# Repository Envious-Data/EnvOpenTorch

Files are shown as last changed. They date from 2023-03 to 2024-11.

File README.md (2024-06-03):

# EnvOpenTorch
 A open source rechargable LED Torch

## Notes
This design is a bit jank and can certaily do with some improvement, If you feel like doing that then please do so and make a PR.

Generally speaking is to have a decently powerful open source LED torch, Im hoping for 10K lumens and some basic brightness control, anything else is bonnus features but there are some i'd like such as PD charging and being able to act as a battery bank if needed.

## Future plans
Im probably going to sell this as a full unit or kit other than the need to supply your own cells, I havent decided on 3S2P or 6S1P but for the time being the charge circuit can handle upto 4S.

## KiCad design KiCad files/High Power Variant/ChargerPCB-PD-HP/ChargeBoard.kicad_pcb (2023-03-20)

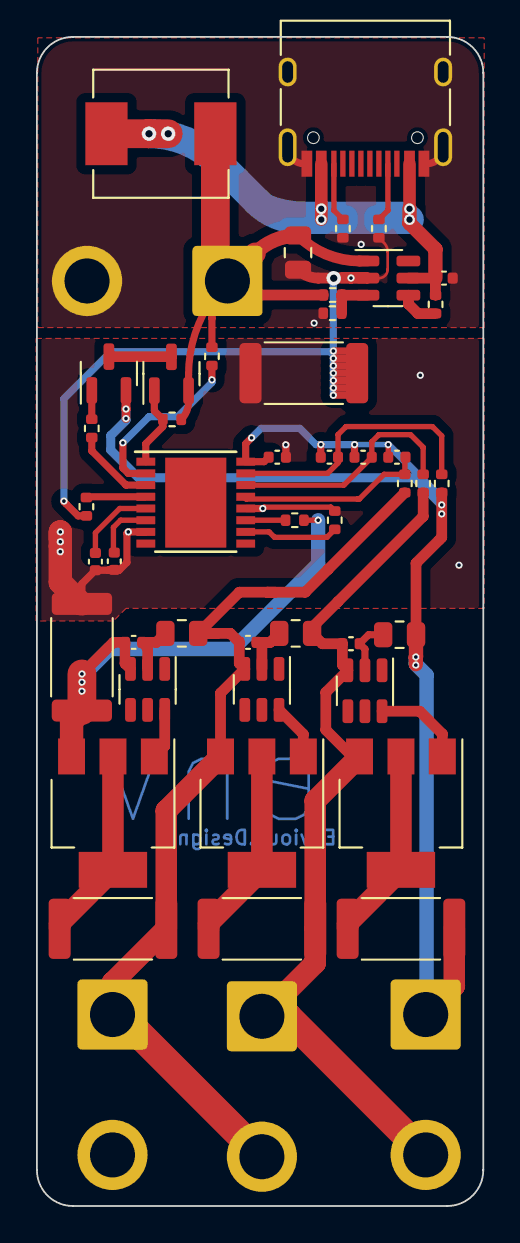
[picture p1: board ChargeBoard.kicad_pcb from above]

Board: 2 copper layers, 24.8 x 65.0 mm, 49 parts (0 on the bottom side), 34 nets.

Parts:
BAT1, BAT2, BAT3: Conn_01x02; SolderWire-2sqmm_1x02_P7.8mm_D2mm_OD3.9mm
C1, C2, C3, C6, C7, C8, C9, C10: 0.1uF 0402; C_0402_1005Metric
C4: 22uF 0402; C_0402_1005Metric
C5: 22uF 0805 25V; C_0805_2012Metric
C11: 2.2uF 0402; C_0402_1005Metric
J1: USB_C_Receptacle_USB2.0; USB_C_Receptacle_HRO_TYPE-C-31-M-12
J101: Conn_01x02; SolderWire-2sqmm_1x02_P7.8mm_D2mm_OD3.9mm
L1: 22uH 10A; L_Sunlord_MWSA0605S
Q1, Q2, Q3: BSP89; SOT-223-3_TabPin2
Q4, Q5: AO3401A; SOT-23
R1, R4, R6: 47 2512; R_2512_6332Metric
R2, R3, R5: 100 0805; R_0805_2012Metric
R7: 10K 0402; R_0402_1005Metric
R8, R9, R21, R22: 5.1K 0402; R_0402_1005Metric
R10: 62K 0402; R_0402_1005Metric
R11: 3K 0402; R_0402_1005Metric
R18, R19, R20, R25, R26, R27: 1K 0402; R_0402_1005Metric
R23: 1M 0402; R_0402_1005Metric
R24: 0r 2512; R_2512_6332Metric
R103: 51r 2512; R_2512_6332Metric
U1, U2, U3: HY2213; SOT-23-6
U4: MT3608; SOT-23-6
U9: 8254; HTSSOP-16-1EP_4.4x5mm_P0.65mm_EP3.4x5mm

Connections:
+12V: C5.1, J101.1, L1.2, Q4.2 (S), R10.1, R22.2, R23.2, U4.1 (SW)
/VDD: BAT3.1, C6.1, C7.1, C8.1, C11.1, Q5.2 (S), R5.1, R6.1, R27.2, U9.16 (VDD)
/VSS: C9.2, C10.2, C11.2, R18.2, R24.2, R103.2, U9.7 (VSS), U9.12 (VCC4)
GND: C4.2, C5.2, J1.A1 (GND), J1.A12 (GND), J1.B1 (GND), J1.B12 (GND), J1.S1 (SHIELD), J101.2, R8.1, R9.1, R11.2, R20.1, R24.1, U4.2 (GND)
unnamed: BAT1.1, BAT2.2, C2.2, Q2.3 (S), R1.1, R2.1, R25.2, U2.3 (VSS)
unnamed: BAT1.2, C1.2, Q1.3 (S), R19.2, R103.1, U1.3 (VSS)
unnamed: BAT2.1, BAT3.2, C3.2, Q3.3 (S), R3.1, R4.1, R26.2, U3.3 (VSS)
unnamed: J1.A5 (CC1), R8.2
unnamed: J1.B5 (CC2), R9.2
unnamed: Q1.2 (D), R1.2
unnamed: Q1.1 (G), U1.6 (Out)
unnamed: Q2.2 (D), R4.2
unnamed: Q2.1 (G), U2.6 (Out)
unnamed: Q3.2 (D), R6.2
unnamed: Q3.1 (G), U3.6 (Out)
unnamed: Q4.3 (D), Q5.3 (D)
unnamed: Q4.1 (G), R23.1, U9.1 (COP)
unnamed: Q5.1 (G), R21.2
unnamed: C1.1, R2.2, U1.2 (VDD)
unnamed: C2.1, R3.2, U2.2 (VDD)
unnamed: C3.1, R5.2, U3.2 (VDD)
unnamed: R7.1, U4.4 (EN)
unnamed: R10.2, R11.1, U4.3 (FB)
unnamed: C9.1, U9.6 (CCT)
unnamed: C10.1, U9.5 (CDT)
unnamed: R19.1, U9.11 (CTL)
unnamed: R21.1, U9.3 (DOP)
unnamed: R18.1, U9.10 (SEL)
unnamed: C6.2, R27.1, U9.15 (VCC1)
unnamed: C7.2, R26.1, U9.14 (VCC2)
unnamed: C8.2, R25.1, U9.13 (VCC3)
unnamed: R20.2, U9.4 (VINI)
unnamed: R22.1, U9.2 (VMP)
VBUS: C4.1, J1.A4 (VBUS), J1.A9 (VBUS), J1.B4 (VBUS), J1.B9 (VBUS), L1.1, R7.2, U4.5 (IN)

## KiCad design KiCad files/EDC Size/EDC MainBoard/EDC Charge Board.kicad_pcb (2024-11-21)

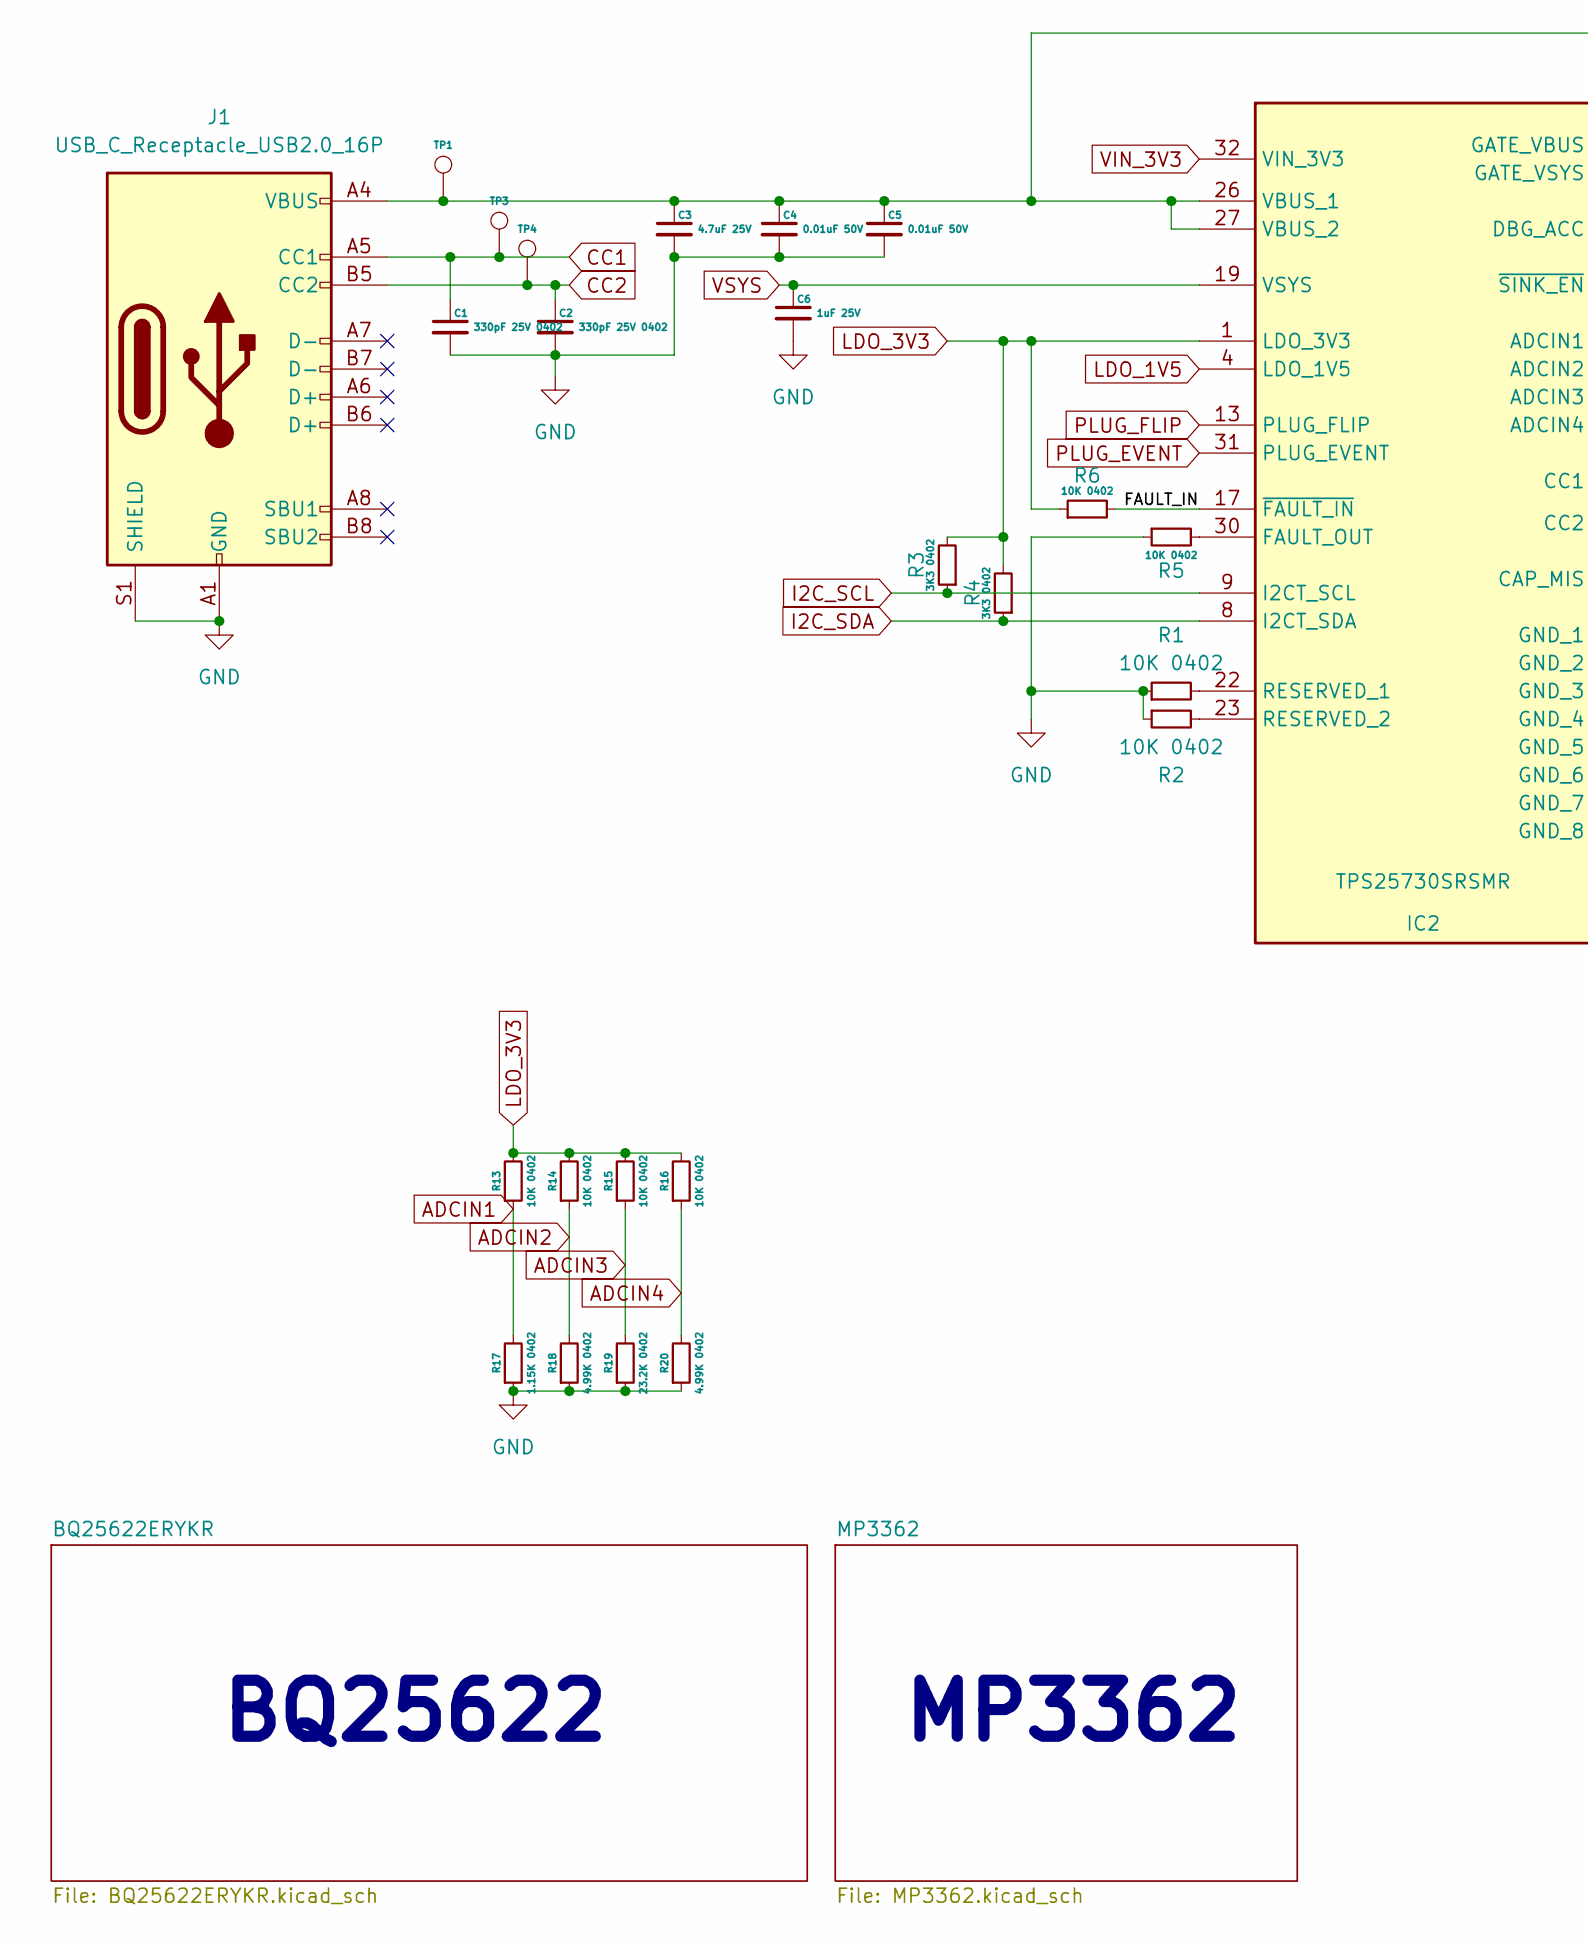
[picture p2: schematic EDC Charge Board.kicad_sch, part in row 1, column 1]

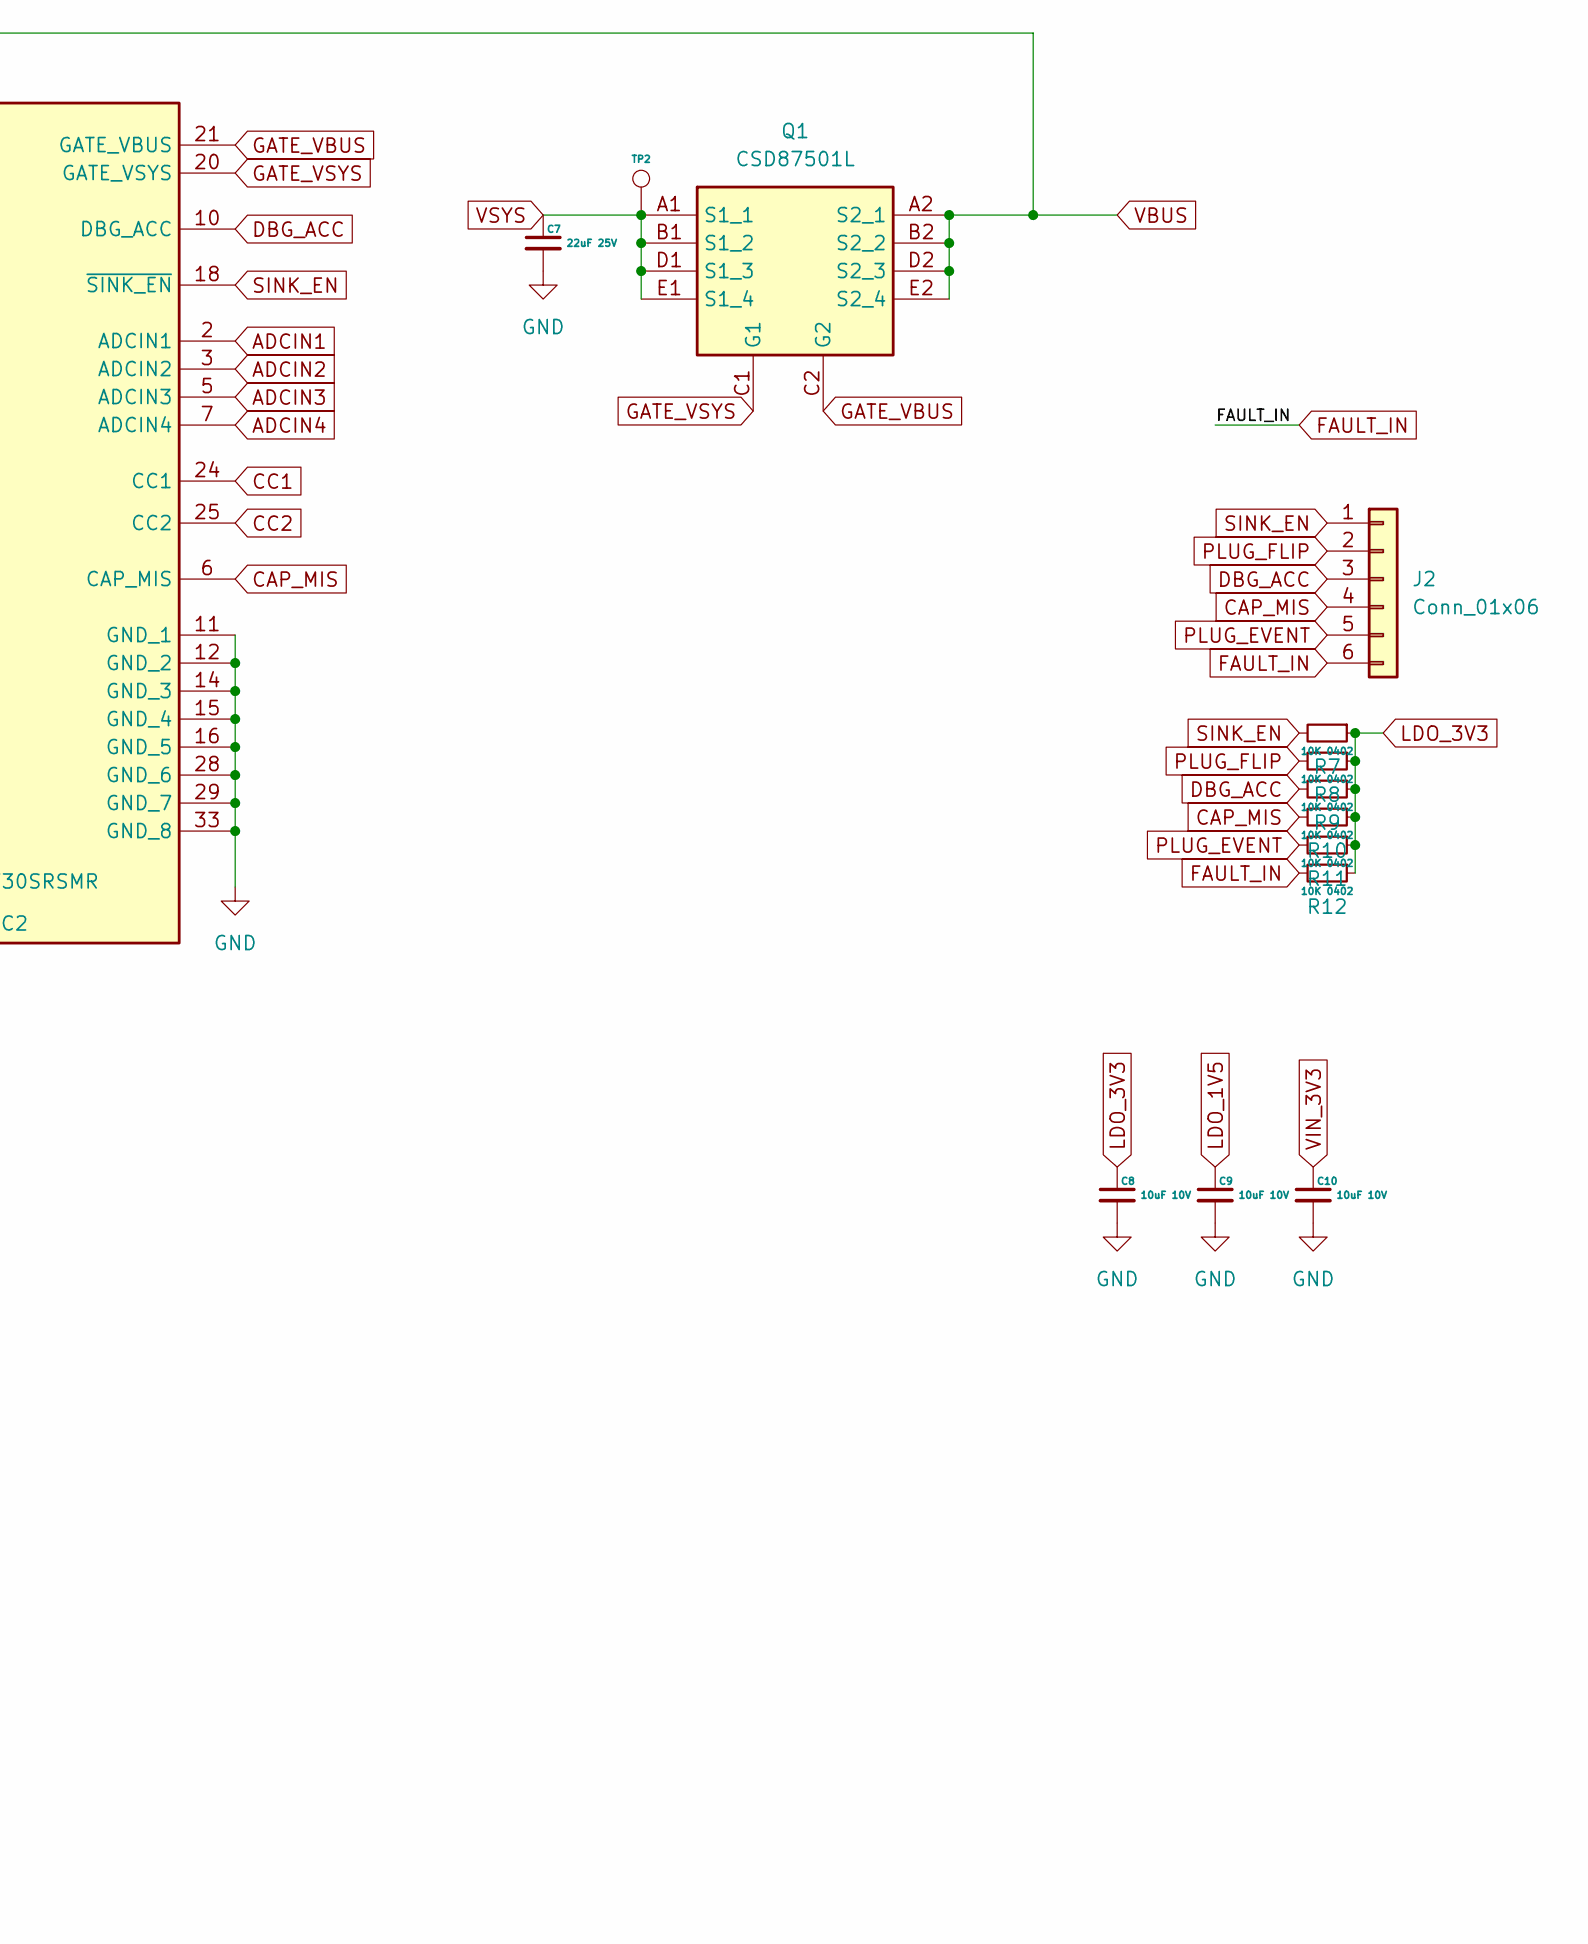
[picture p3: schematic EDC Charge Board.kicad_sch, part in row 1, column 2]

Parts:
C1, C2: 330pF 25V 0402; C_0402_1005Metric
C3: 4.7uF 25V; C_0402_1005Metric
C4, C5: 0.01uF 50V; C_0402_1005Metric
C6: 1uF 25V; C_0402_1005Metric
C7: 22uF 25V; C_0402_1005Metric
C8, C9, C10: 10uF 10V; C_0402_1005Metric
IC2: TPS25730SRSMR; QFN40P400X400X100-33N-D; Mouser Part Number 595-TPS25730SRSMR
J1: USB_C_Receptacle_USB2.0_16P; USB_C_Receptacle_HRO_TYPE-C-31-M-12
J2: Conn_01x06; PinHeader_1x06_P2.54mm_Vertical
Q1: CSD87501L; Mouser Part Number 595-CSD87501L
R1, R2, R5, R6, R7, R8, R9, R10, R11, R12, R13, R14, R15, R16: 10K 0402; R_0402_1005Metric
R3, R4: 3K3 0402; R_0402_1005Metric
R17: 1.15K 0402; R_0402_1005Metric
R18, R20: 4.99K 0402; R_0402_1005Metric
R19: 23.2K 0402; R_0402_1005Metric
TP1, TP2, TP3, TP4: TestPoint; TestPoint_Pad_D1.0mm

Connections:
ADCIN1: IC2.2 (ADCIN1), R13.1, R17.2
ADCIN2: IC2.3 (ADCIN2), R14.1, R18.2
ADCIN3: IC2.5 (ADCIN3), R15.1, R19.2
ADCIN4: IC2.7 (ADCIN4), R16.1, R20.2
CAP_MIS: IC2.6 (CAP_MIS), J2.4, R10.2
CC1: C1.1, IC2.24 (CC1), J1.A5 (CC1), TP3.1
CC2: C2.1, IC2.25 (CC2), J1.B5 (CC2), TP4.1
DBG_ACC: IC2.10 (DBG_ACC), J2.3, R9.2
FAULT_IN: IC2.17 (~FAULT_IN), J2.6, R6.2, R12.2
GATE_VBUS: IC2.21 (GATE_VBUS), Q1.C2 (G2)
GATE_VSYS: IC2.20 (GATE_VSYS), Q1.C1 (G1)
GND: C1.2, C2.2, C3.2, C4.2, C5.2, C6.2, C7.2, C8.2, C9.2, C10.2, IC2.11 (GND_1), IC2.12 (GND_2), IC2.14 (GND_3), IC2.15 (GND_4), IC2.16 (GND_5), IC2.28 (GND_6), IC2.29 (GND_7), IC2.33 (GND_8), J1.A1 (GND), J1.A12 (GND), J1.B1 (GND), J1.B12 (GND), J1.S1 (SHIELD), R1.1, R2.1, R5.1, R17.1, R18.1, R19.1, R20.1; also elsewhere on the board
I2C_SCL: IC2.9 (I2CT_SCL), R3.1; also elsewhere on the board
I2C_SDA: IC2.8 (I2CT_SDA), R4.1; also elsewhere on the board
LDO_1V5: C9.1, IC2.4 (LDO_1V5)
LDO_3V3: C8.1, IC2.1 (LDO_3V3), R3.2, R4.2, R6.1, R7.1, R8.1, R9.1, R10.1, R11.1, R12.1, R13.2, R14.2, R15.2, R16.2
unnamed: IC2.30 (FAULT_OUT), R5.2
unnamed: IC2.22 (RESERVED_1), R1.2
unnamed: IC2.23 (RESERVED_2), R2.2
PLUG_EVENT: IC2.31 (PLUG_EVENT), J2.5, R11.2
PLUG_FLIP: IC2.13 (PLUG_FLIP), J2.2, R8.2
SINK_EN: IC2.18 (~SINK_EN), J2.1, R7.2
VBUS: C3.1, C4.1, C5.1, IC2.26 (VBUS_1), IC2.27 (VBUS_2), J1.A4 (VBUS), J1.A9 (VBUS), J1.B4 (VBUS), J1.B9 (VBUS), Q1.A2 (S2_1), Q1.B2 (S2_2), Q1.D2 (S2_3), Q1.E2 (S2_4), TP1.1
VIN_3V3: C10.1, IC2.32 (VIN_3V3)
VSYS: C6.1, C7.1, IC2.19 (VSYS), Q1.A1 (S1_1), Q1.B1 (S1_2), Q1.D1 (S1_3), Q1.E1 (S1_4), TP2.1; also elsewhere on the board

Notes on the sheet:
MP3362
BQ25622

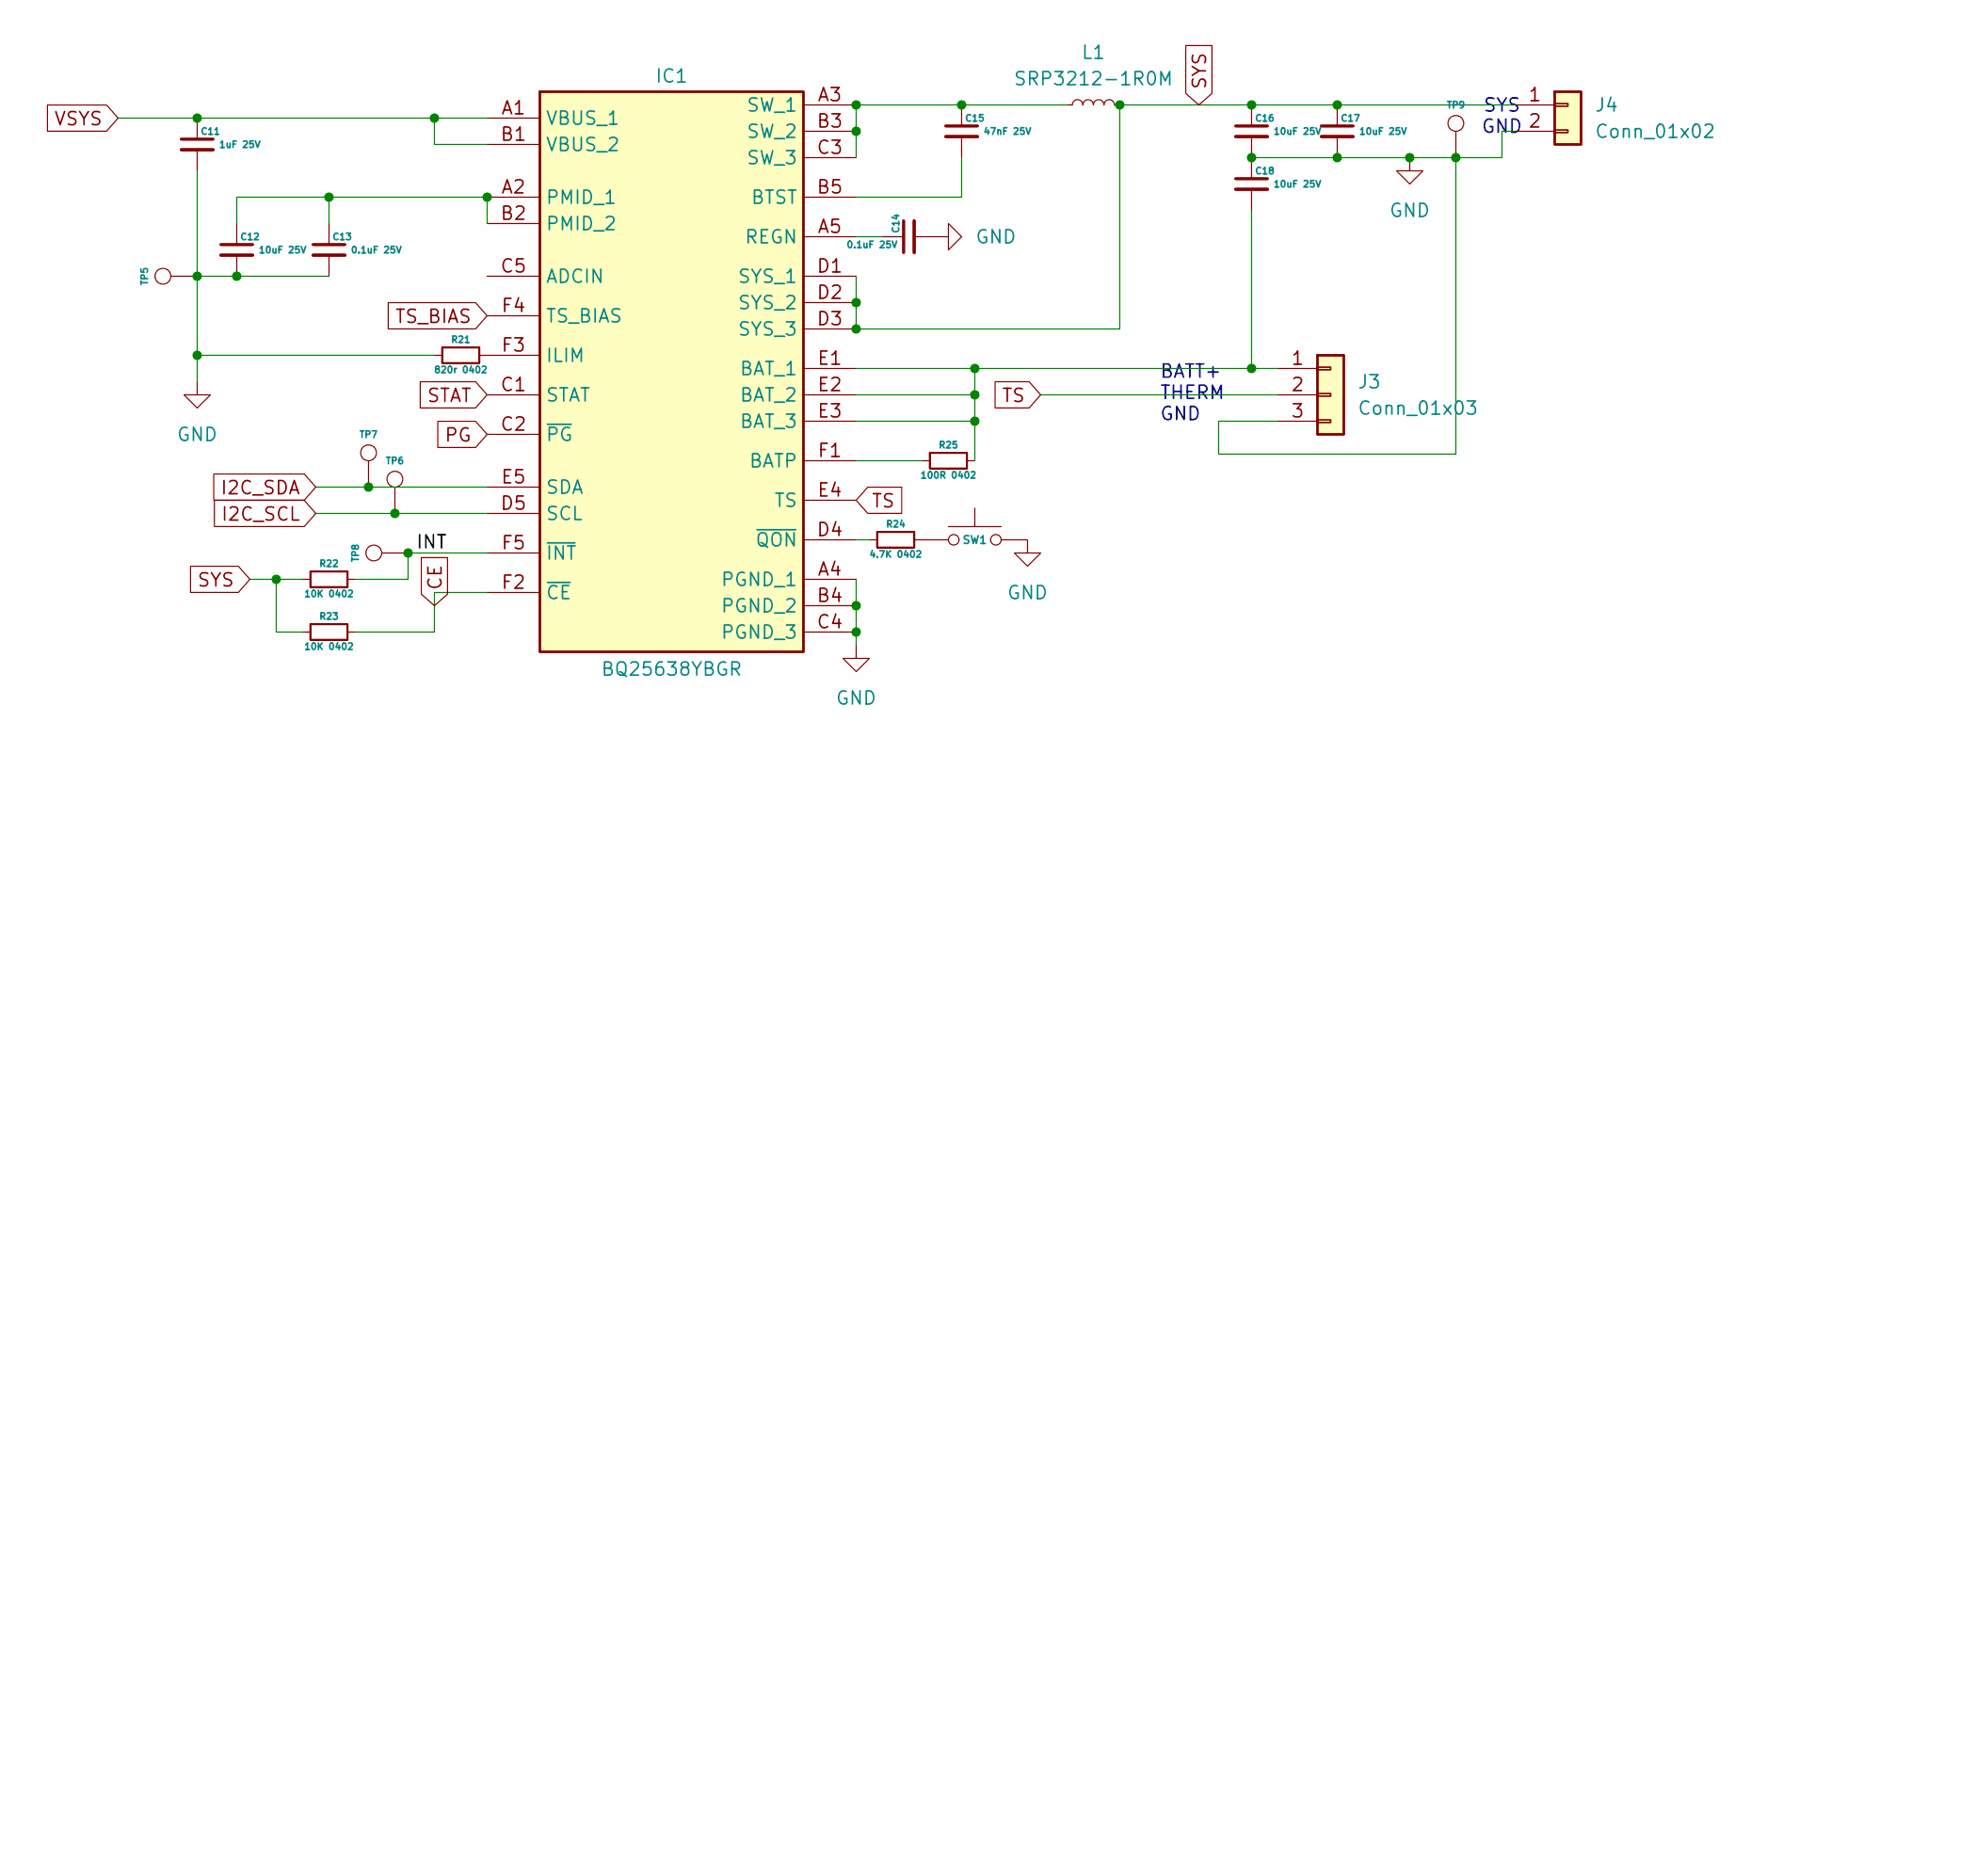
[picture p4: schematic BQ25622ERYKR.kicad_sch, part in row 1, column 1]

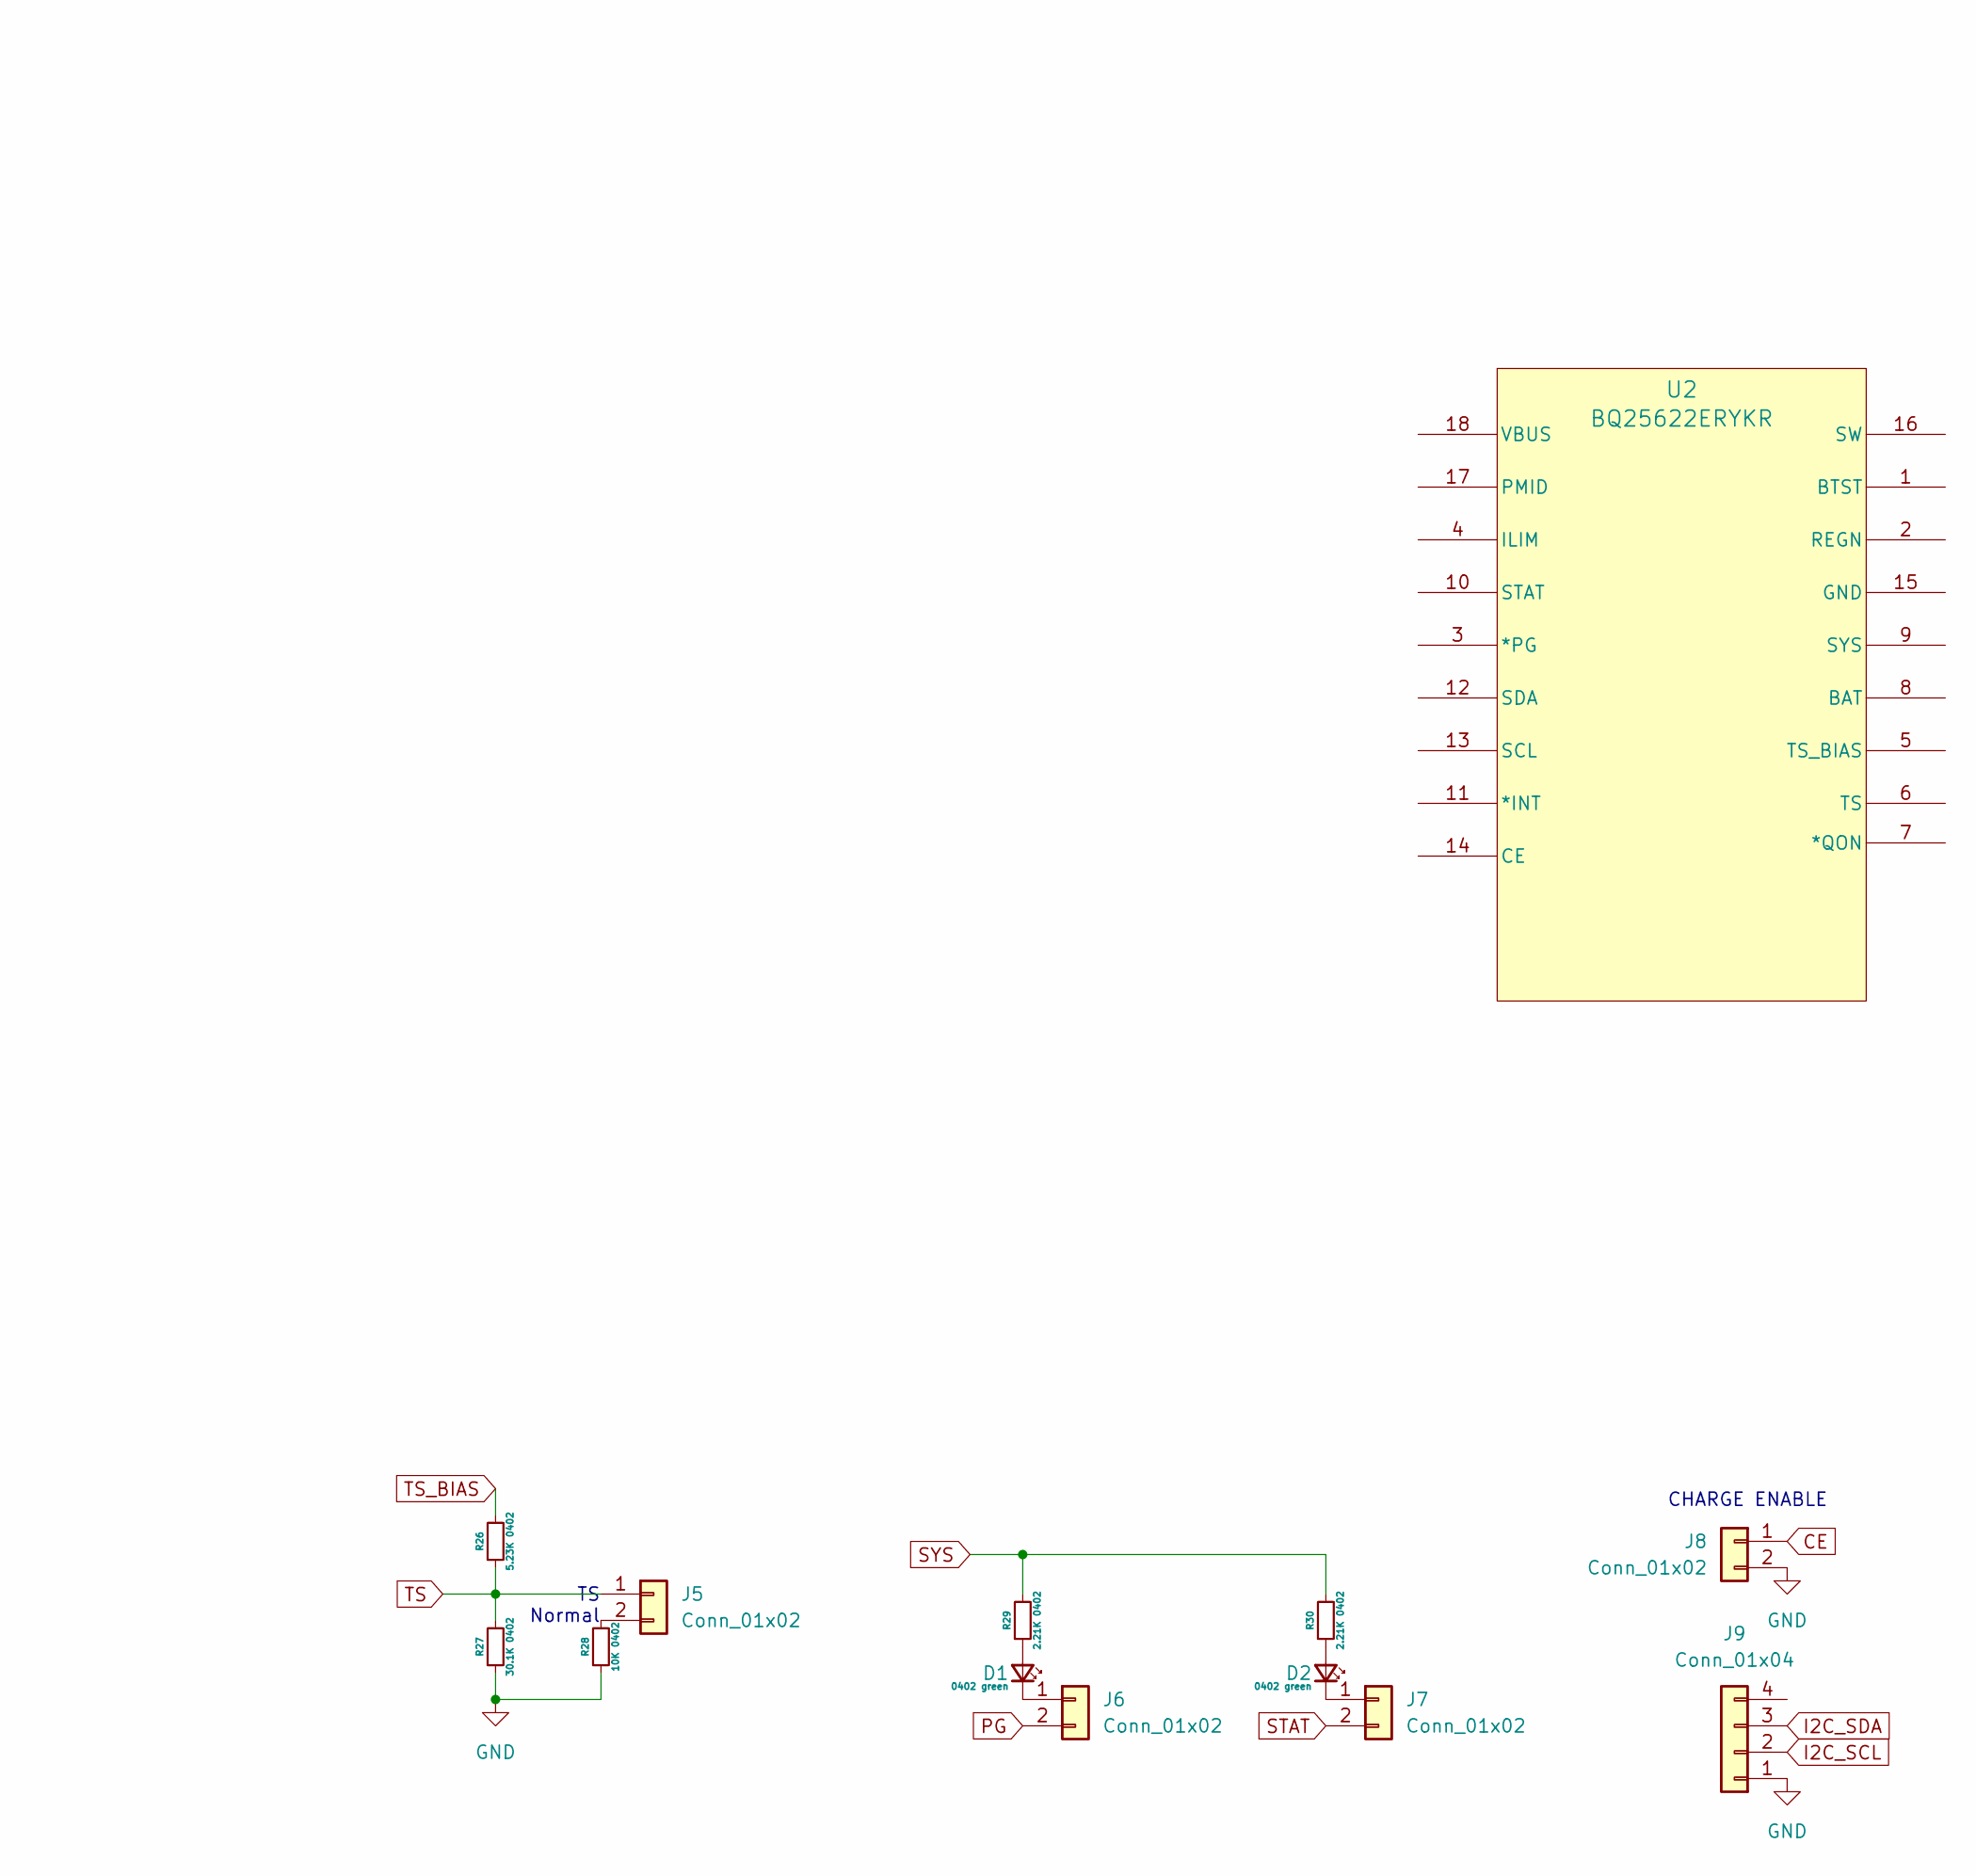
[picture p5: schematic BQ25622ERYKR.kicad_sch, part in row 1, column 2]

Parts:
C11: 1uF 25V; C_0402_1005Metric
C12, C16, C17, C18: 10uF 25V; C_0402_1005Metric
C13, C14: 0.1uF 25V; C_0402_1005Metric
C15: 47nF 25V; C_0402_1005Metric
D1, D2: 0402 green; LED_0402_1005Metric
IC1: BQ25638YBGR; BGA30C40P5X6_227X198X50; Mouser Part Number 595-BQ25638YBGR
J3: Conn_01x03; PinHeader_1x03_P2.54mm_Vertical
J4: Conn_01x02; PinHeader_1x02_P2.54mm_Vertical
J5, J6, J7: Conn_01x02; SolderJumper-2_P1.3mm_Open_RoundedPad1.0x1.5mm
J8: Conn_01x02; SolderJumper-2_P1.3mm_Bridged_RoundedPad1.0x1.5mm
J9: Conn_01x04; PinSocket_1x04_P2.54mm_Vertical
L1: SRP3212-1R0M; L_Wurth_WE-LQSH-3012
R21: 820r 0402; R_0402_1005Metric
R22, R23, R28: 10K 0402; R_0402_1005Metric
R24: 4.7K 0402; R_0402_1005Metric
R25: 100R 0402; R_0402_1005Metric
R26: 5.23K 0402; R_0402_1005Metric
R27: 30.1K 0402; R_0402_1005Metric
R29, R30: 2.21K 0402; R_0402_1005Metric
SW1: SW_Push; SW_SPST_B3U-1000P
TP5, TP6, TP7, TP8, TP9: TestPoint; TestPoint_Pad_D1.0mm
U2: BQ25622ERYKR; WQFN-HR18_RYK_TEX

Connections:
/BQ25638/INT: IC1.F5 (~INT), R22.2, TP8.1
CE: IC1.F2 (~CE), J8.1, R23.2
GND: C11.2, C12.2, C13.2, C14.2, C16.2, C17.2, C18.1, IC1.A4 (PGND_1), IC1.B4 (PGND_2), IC1.C4 (PGND_3), J3.3, J4.2, J8.2, J9.1, R21.1, R27.1, R28.1, SW1.2, TP5.1, TP9.1; also elsewhere on the board
I2C_SCL: IC1.D5 (SCL), J9.2, TP6.1; also elsewhere on the board
I2C_SDA: IC1.E5 (SDA), J9.3, TP7.1; also elsewhere on the board
unnamed: D1.2 (A), R29.1
unnamed: D1.1 (K), J6.1
unnamed: D2.2 (A), R30.1
unnamed: D2.1 (K), J7.1
unnamed: IC1.F1 (BATP), R25.1
unnamed: C18.2, IC1.E1 (BAT_1), IC1.E2 (BAT_2), IC1.E3 (BAT_3), J3.1, R25.2
unnamed: C15.2, IC1.B5 (BTST)
unnamed: IC1.F3 (ILIM), R21.2
unnamed: C12.1, C13.1, IC1.A2 (PMID_1), IC1.B2 (PMID_2)
unnamed: C14.1, IC1.A5 (REGN)
unnamed: C15.1, IC1.A3 (SW_1), IC1.B3 (SW_2), IC1.C3 (SW_3), L1.1
unnamed: IC1.D4 (~QON), R24.1
unnamed: J5.2, R28.2
unnamed: R24.2, SW1.1
PG: IC1.C2 (~PG), J6.2
STAT: IC1.C1 (STAT), J7.2
SYS: C16.1, C17.1, IC1.D1 (SYS_1), IC1.D2 (SYS_2), IC1.D3 (SYS_3), J4.1, L1.2, R22.1, R23.1, R29.2, R30.2; also elsewhere on the board
TS: IC1.E4 (TS), J3.2, J5.1, R26.1, R27.2
TS_BIAS: IC1.F4 (TS_BIAS), R26.2
VSYS: C11.1, IC1.A1 (VBUS_1), IC1.B1 (VBUS_2); also elsewhere on the board

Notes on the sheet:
CHARGE ENABLE
TS Normal
BATT+ THERM GND
SYS GND

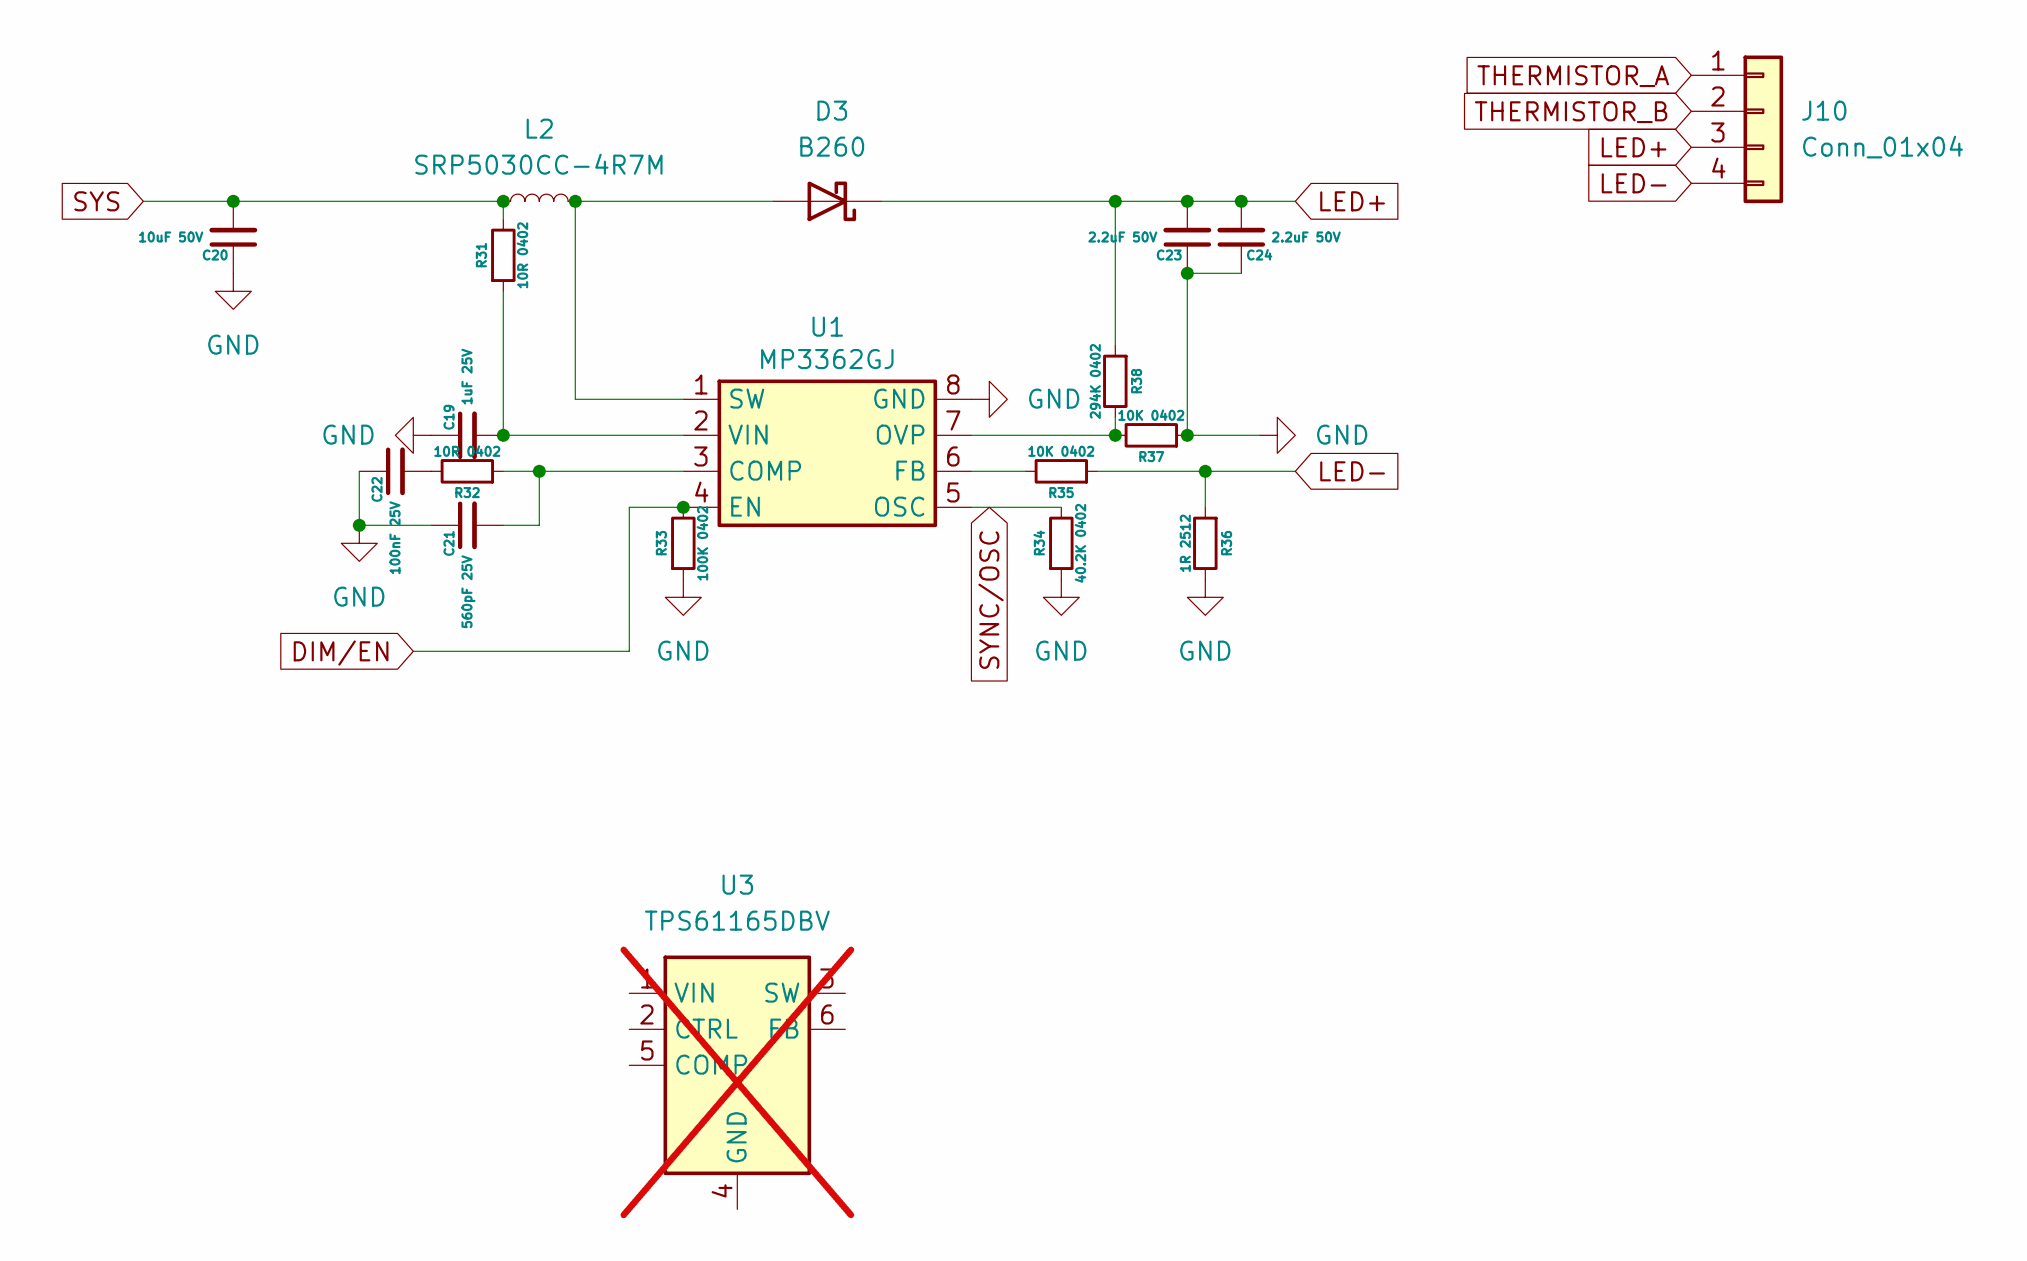
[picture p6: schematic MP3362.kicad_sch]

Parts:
C19: 1uF 25V; C_0402_1005Metric
C20: 10uF 50V; C_0402_1005Metric
C21: 560pF 25V; C_0402_1005Metric
C22: 100nF 25V; C_0402_1005Metric
C23, C24: 2.2uF 50V; C_0402_1005Metric
D3: B260; D_SMB
J10: Conn_01x04; PinSocket_1x04_P2.54mm_Vertical
L2: SRP5030CC-4R7M; L_Bourns_SRP5030T
R31, R32: 10R 0402; R_0402_1005Metric
R33: 100K 0402; R_0402_1005Metric
R34: 40.2K 0402; R_0402_1005Metric
R35, R37: 10K 0402; R_0402_1005Metric
R36: 1R 2512; R_2512_6332Metric
R38: 294K 0402; R_0402_1005Metric
U1: MP3362GJ; TSOT-23-8
U3: TPS61165DBV; SOT-23-6_Handsoldering; not fitted

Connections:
DIM/EN: R33.2, U1.4 (EN)
GND: C19.1, C20.1, C21.1, C22.1, C23.1, C24.1, R33.1, R34.1, R36.2, R37.1, U1.8 (GND); also elsewhere on the board
LED+: C23.2, C24.2, D3.1 (K), J10.3, R38.1
LED-: J10.4, R35.1, R36.1
unnamed: C22.2, R32.2
unnamed: D3.2 (A), L2.2, U1.1 (SW)
unnamed: C21.2, R32.1, U1.3 (COMP)
unnamed: R35.2, U1.6 (FB)
unnamed: R37.2, R38.2, U1.7 (OVP)
unnamed: C19.2, R31.1, U1.2 (VIN)
SYNC/OSC: R34.2, U1.5 (OSC)
SYS: C20.2, L2.1, R31.2; also elsewhere on the board
THERMISTOR_A: J10.1
THERMISTOR_B: J10.2

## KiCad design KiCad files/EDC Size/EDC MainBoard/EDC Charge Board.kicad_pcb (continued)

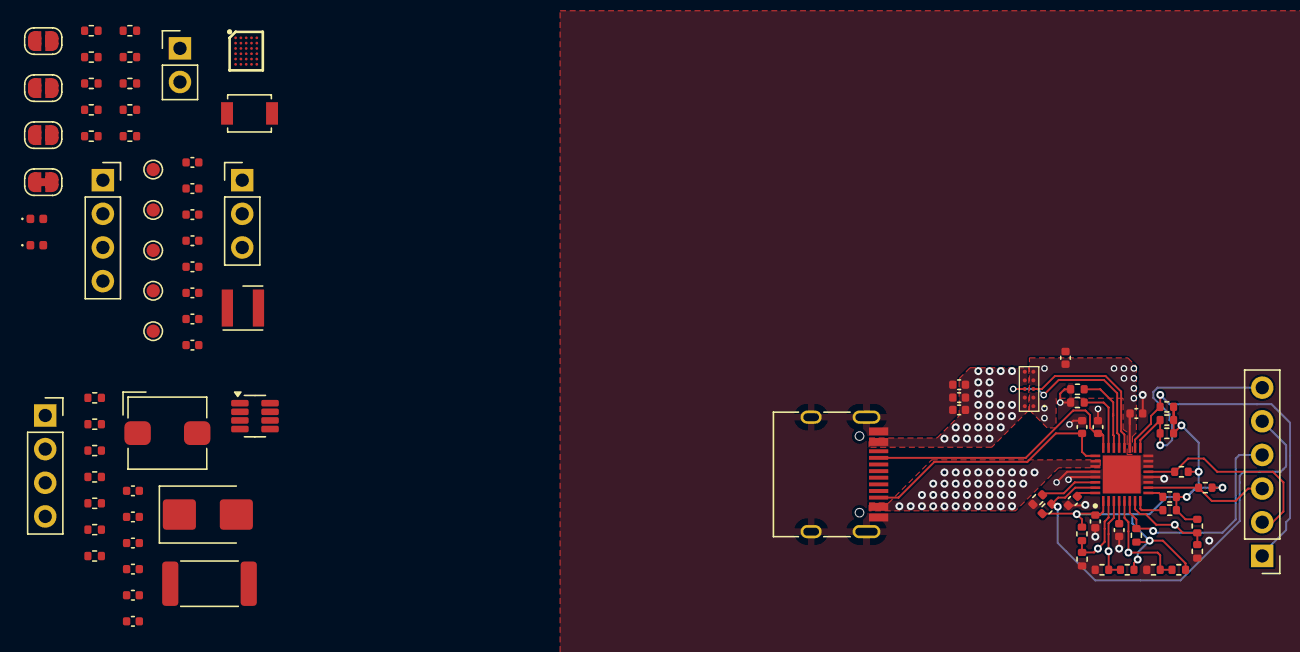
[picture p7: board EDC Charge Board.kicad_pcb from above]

Board: 2 copper layers, 87 parts (0 on the bottom side), 56 nets.

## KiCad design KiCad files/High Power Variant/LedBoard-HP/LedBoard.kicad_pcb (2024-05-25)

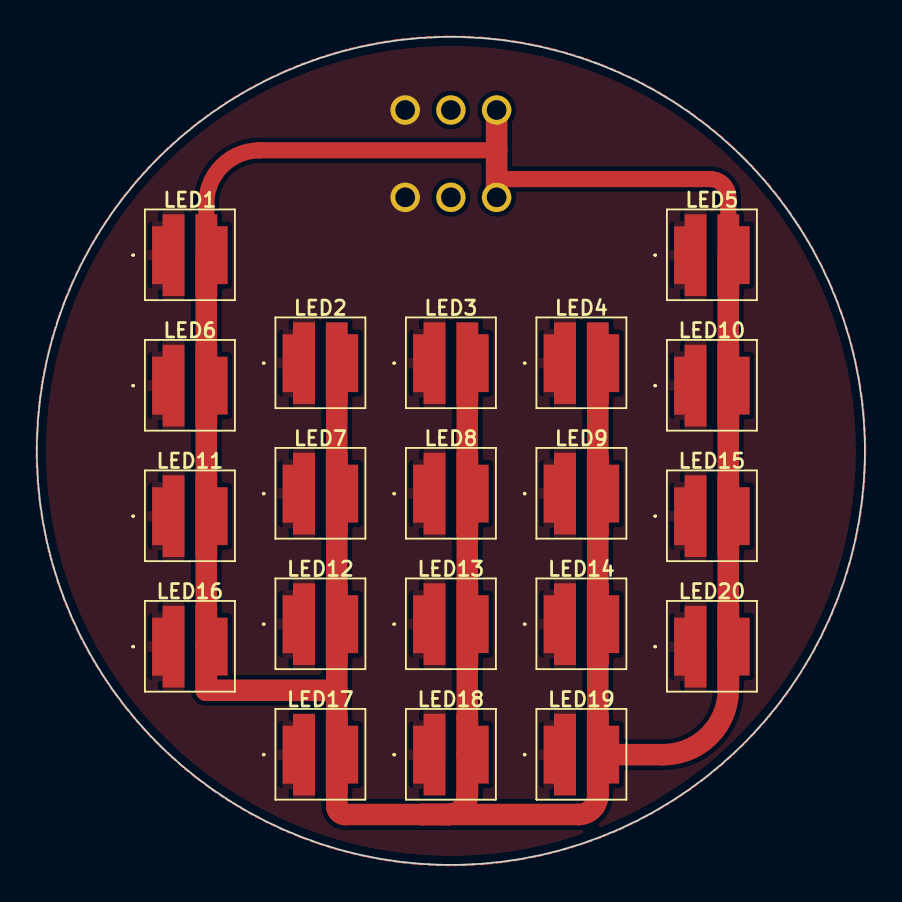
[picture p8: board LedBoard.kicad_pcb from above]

Board: 2 copper layers, 46.0 x 46.0 mm, 21 parts (1 on the bottom side), 2 nets.

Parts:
J4: 7-5530843-7; 755308437
LED1, LED2, LED3, LED4, LED5, LED6, LED7, LED8, LED9, LED10, LED11, LED12, LED13, LED14, LED15, LED16, LED17, LED18, LED19, LED20: L1505790500600000

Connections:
GND: J4.5, J4.6, LED1.1 (K_1), LED1.3 (K_2), LED2.1 (K_1), LED2.3 (K_2), LED3.1 (K_1), LED3.3 (K_2), LED4.1 (K_1), LED4.3 (K_2), LED5.1 (K_1), LED5.3 (K_2), LED6.1 (K_1), LED6.3 (K_2), LED7.1 (K_1), LED7.3 (K_2), LED8.1 (K_1), LED8.3 (K_2), LED9.1 (K_1), LED9.3 (K_2), LED10.1 (K_1), LED10.3 (K_2), LED11.1 (K_1), LED11.3 (K_2), LED12.1 (K_1), LED12.3 (K_2), LED13.1 (K_1), LED13.3 (K_2), LED14.1 (K_1), LED14.3 (K_2), LED15.1 (K_1), LED15.3 (K_2), LED16.1 (K_1), LED16.3 (K_2), LED17.1 (K_1), LED17.3 (K_2), LED18.1 (K_1), LED18.3 (K_2), LED19.1 (K_1), LED19.3 (K_2), LED20.1 (K_1), LED20.3 (K_2)
VCC: J4.1, J4.2, LED1.2 (A_1), LED1.4 (A_2), LED2.2 (A_1), LED2.4 (A_2), LED3.2 (A_1), LED3.4 (A_2), LED4.2 (A_1), LED4.4 (A_2), LED5.2 (A_1), LED5.4 (A_2), LED6.2 (A_1), LED6.4 (A_2), LED7.2 (A_1), LED7.4 (A_2), LED8.2 (A_1), LED8.4 (A_2), LED9.2 (A_1), LED9.4 (A_2), LED10.2 (A_1), LED10.4 (A_2), LED11.2 (A_1), LED11.4 (A_2), LED12.2 (A_1), LED12.4 (A_2), LED13.2 (A_1), LED13.4 (A_2), LED14.2 (A_1), LED14.4 (A_2), LED15.2 (A_1), LED15.4 (A_2), LED16.2 (A_1), LED16.4 (A_2), LED17.2 (A_1), LED17.4 (A_2), LED18.2 (A_1), LED18.4 (A_2), LED19.2 (A_1), LED19.4 (A_2), LED20.2 (A_1), LED20.4 (A_2)

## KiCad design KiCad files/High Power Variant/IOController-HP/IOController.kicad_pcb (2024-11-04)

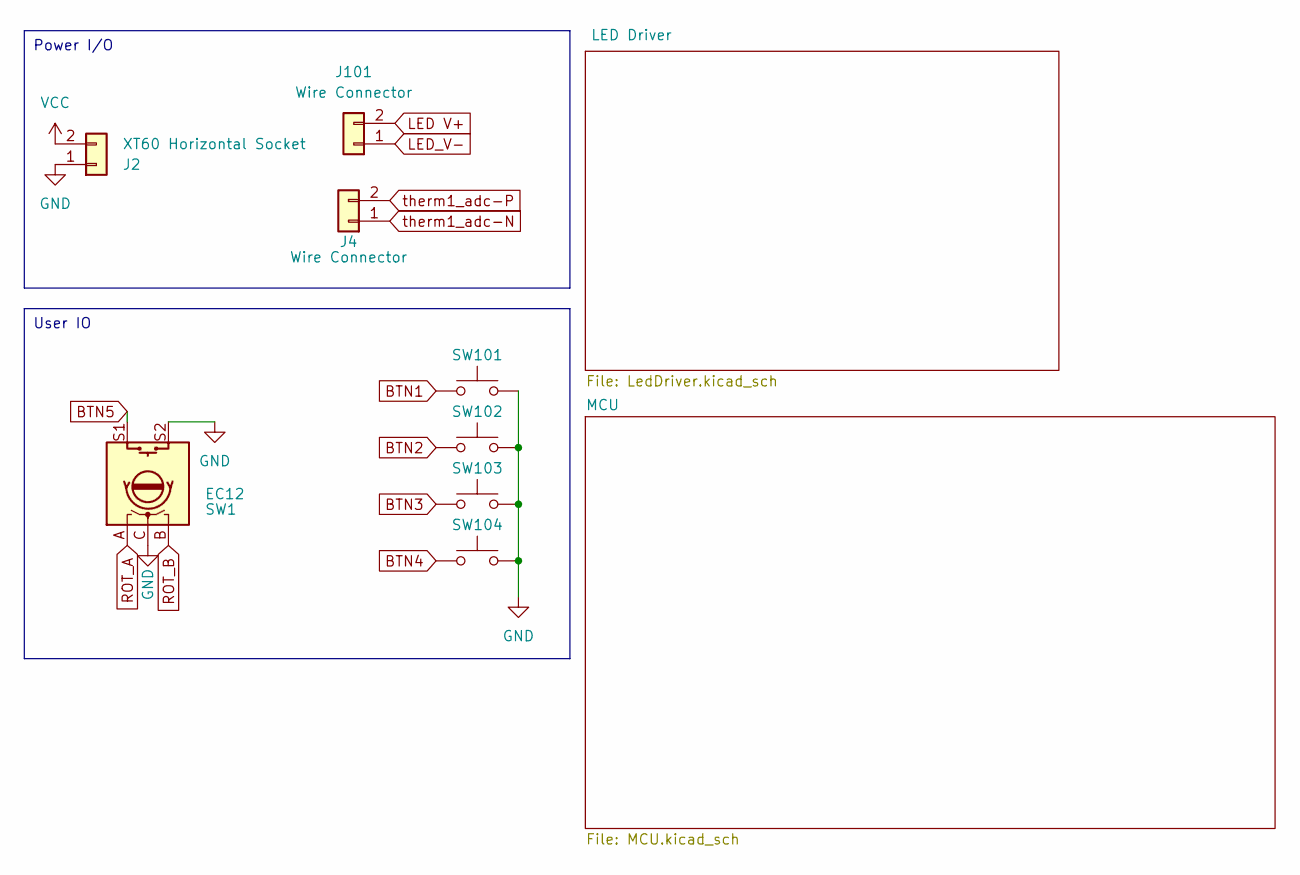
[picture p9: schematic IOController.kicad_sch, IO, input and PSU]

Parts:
J2: XT60 Horizontal Socket; AMASS_XT60PW-F_1x02_P7.20mm_Horizontal
J4, J101: Wire Connector; SolderWire-0.5sqmm_1x02_P4.8mm_D0.9mm_OD2.3mm
SW1: EC12; RotaryEncoder_Alps_EC12E-Switch_Vertical_H20mm_CircularMoun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
SW101, SW102, SW103, SW104: B3U; SW_SPST_B3U-1000P-B

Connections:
BTN1: SW101.1; also elsewhere on the board
BTN2: SW102.1; also elsewhere on the board
BTN3: SW103.1; also elsewhere on the board
BTN4: SW104.1; also elsewhere on the board
BTN5: SW1.S1; also elsewhere on the board
GND: J2.1, SW1.C, SW1.S2, SW101.2, SW102.2, SW103.2, SW104.2; also elsewhere on the board
LED V+: J101.3; also elsewhere on the board
ROT_A: SW1.A; also elsewhere on the board
ROT_B: SW1.B; also elsewhere on the board
VCC: J2.2; also elsewhere on the board
therm1_adc-N: J101.1
therm1_adc-P: J101.4

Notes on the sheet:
Power I/O
User IO

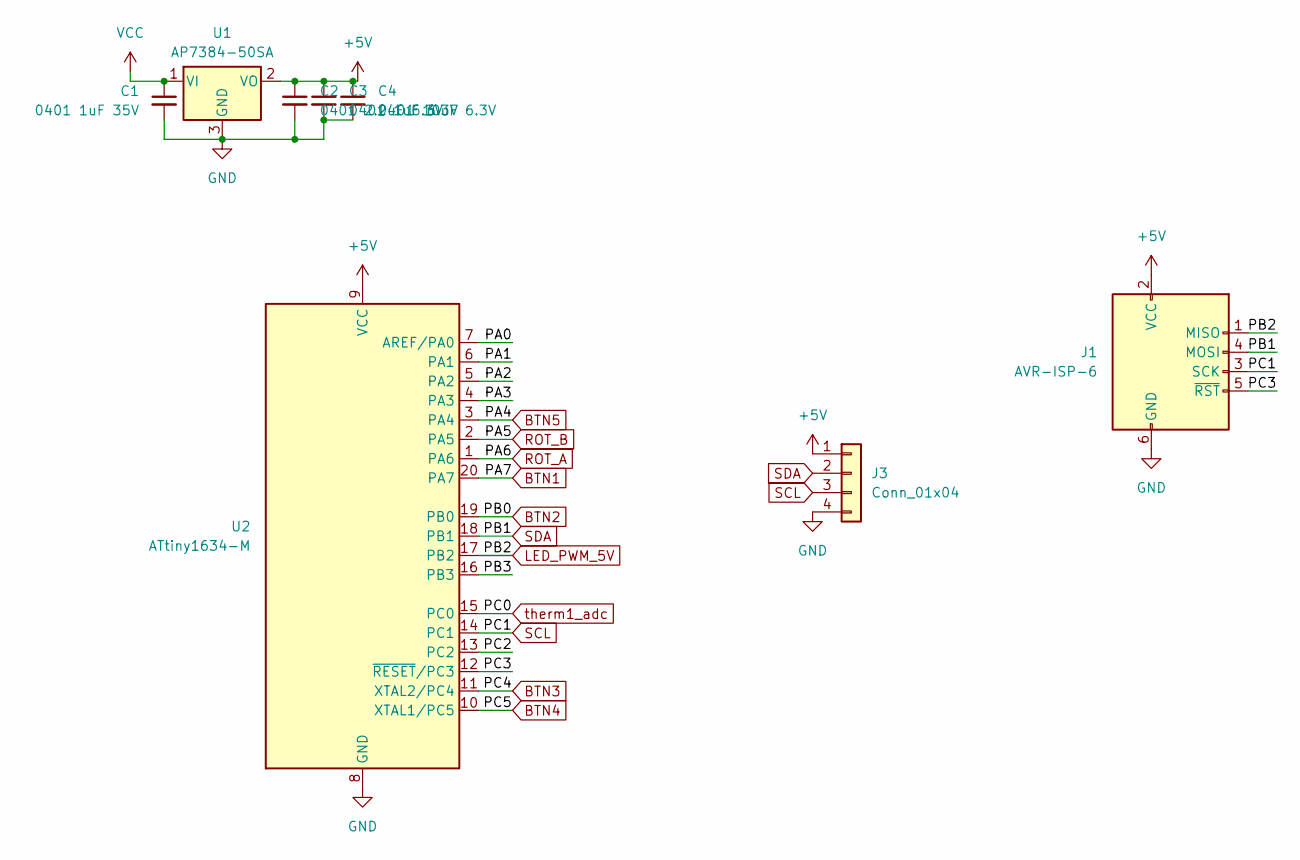
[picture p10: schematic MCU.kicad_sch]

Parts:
C1: 0401 1uF 35V; C_0402_1005Metric
C2: 0401 2.2uF 6.3V; C_0402_1005Metric
C3: 0401 1uF 6.3V; C_0402_1005Metric
C4: 0401 10uF 6.3V; C_0402_1005Metric
J1: AVR-ISP-6; IDC-Header_2x03_P2.54mm_Vertical
J3: Conn_01x04; PinHeader_1x04_P1.00mm_Vertical
U1: AP7384-50SA; SOT-23
U2: ATtiny1634-M; QFN-20-1EP_4x4mm_P0.5mm_EP2.6x2.6mm

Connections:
+5V: C2.1, C3.1, C4.1, J1.2 (VCC), J3.1, U1.2 (VO), U2.9 (VCC)
/MCU/PA0: U2.7 (AREF/PA0)
/MCU/PA1: U2.6 (PA1)
/MCU/PA2: U2.5 (PA2)
/MCU/PA3: U2.4 (PA3)
/MCU/PB3: U2.16 (PB3)
/MCU/PC2: U2.13 (PC2)
/MCU/PC3: J1.5 (~RST), U2.12 (~RESET/PC3)
BTN1: U2.20 (PA7); also elsewhere on the board
BTN2: U2.19 (PB0); also elsewhere on the board
BTN3: U2.11 (XTAL2/PC4); also elsewhere on the board
BTN4: U2.10 (XTAL1/PC5); also elsewhere on the board
BTN5: U2.3 (PA4); also elsewhere on the board
GND: C1.2, C2.2, C3.2, C4.2, J1.6 (GND), J3.4, U1.3 (GND), U2.8 (GND), U2.21 (GND); also elsewhere on the board
LED_PWM_5V: J1.1 (MISO), U2.17 (PB2); also elsewhere on the board
ROT_A: U2.1 (PA6); also elsewhere on the board
ROT_B: U2.2 (PA5); also elsewhere on the board
SCL: J1.3 (SCK), J3.3, U2.14 (PC1)
SDA: J1.4 (MOSI), J3.2, U2.18 (PB1)
VCC: C1.1, U1.1 (VI); also elsewhere on the board
therm1_adc: U2.15 (PC0)

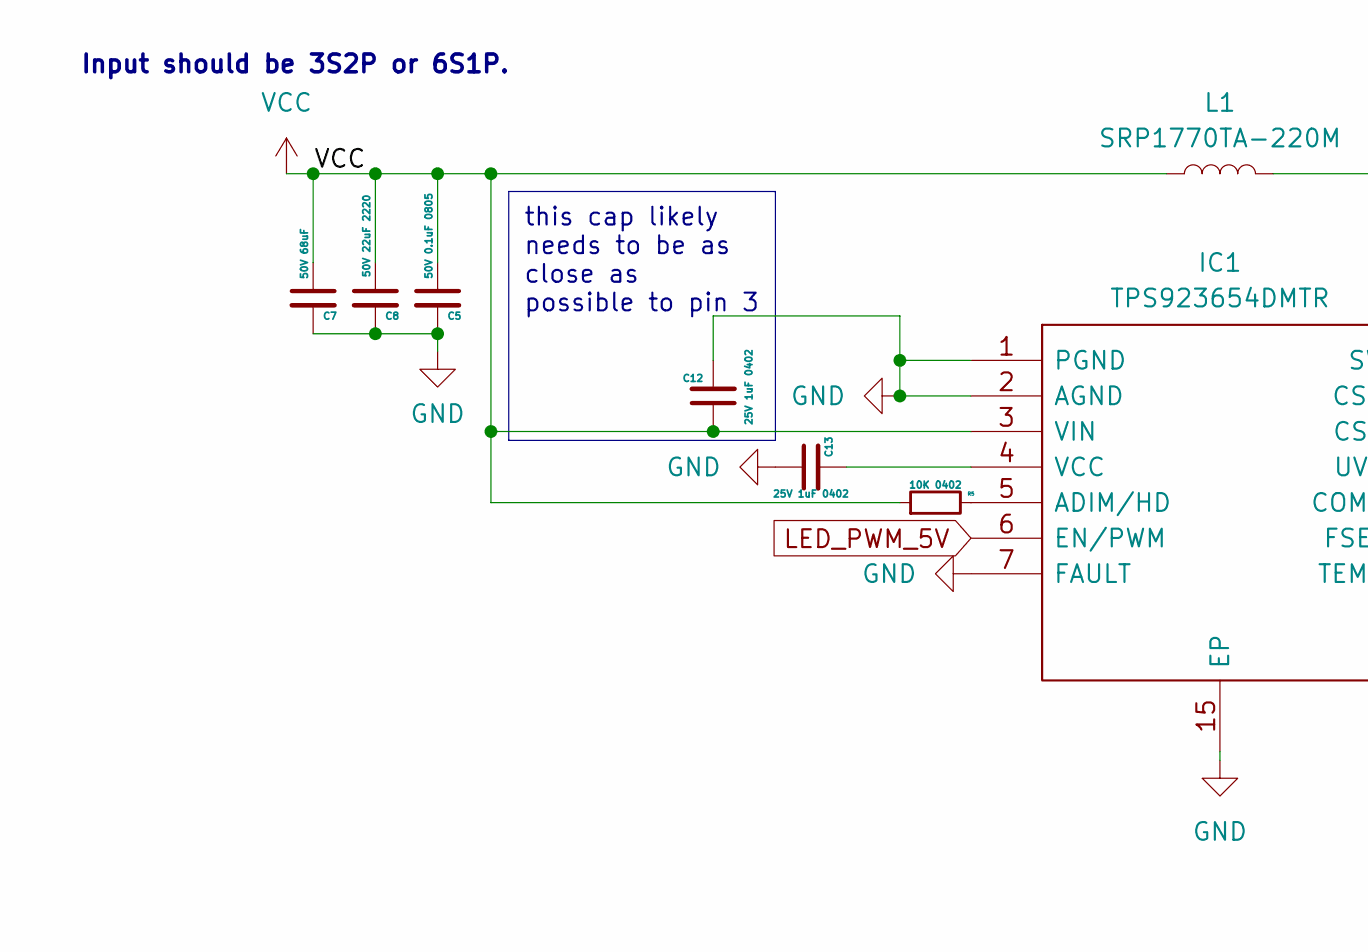
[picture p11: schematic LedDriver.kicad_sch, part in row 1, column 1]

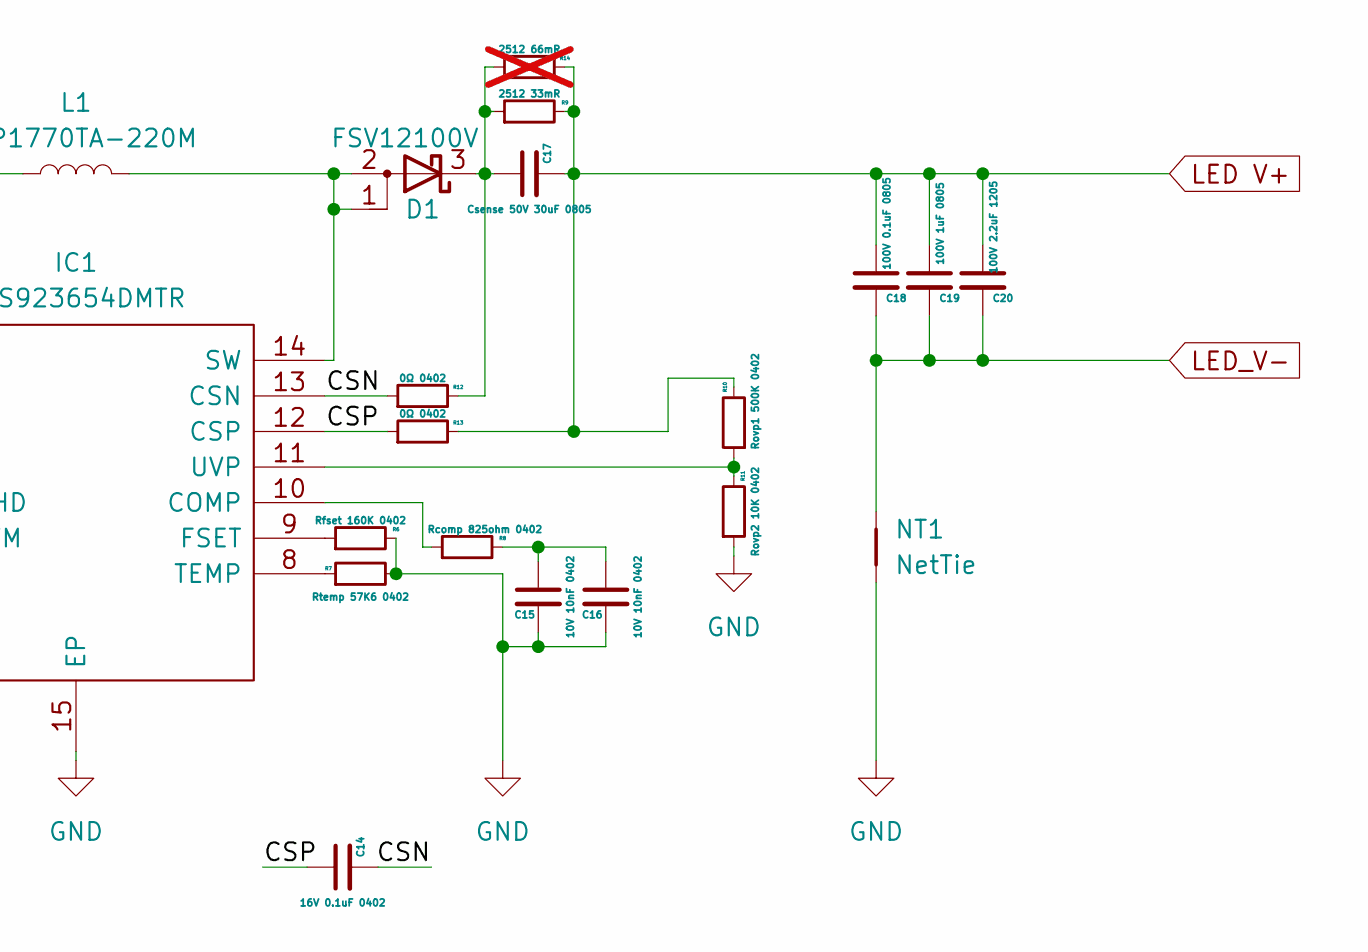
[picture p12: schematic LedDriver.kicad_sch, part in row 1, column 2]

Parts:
C5: 50V 0.1uF 0805; C_0805_2012Metric
C7: 50V 68uF; CP_Elec_6.3x3
C8: 50V 22uF 2220; C_2220_5750Metric
C12, C13: 25V 1uF 0402; C_0402_1005Metric
C14: 16V 0.1uF 0402; C_0402_1005Metric
C15, C16: 10V 10nF 0402; C_0402_1005Metric
C17: Csense 50V 30uF 0805; C_0805_2012Metric
C18: 100V 0.1uF 0805; C_0805_2012Metric
C19: 100V 1uF 0805; C_0805_2012Metric
C20: 100V 2.2uF 1205; C_1206_3216Metric
D1: FSV12100V; TO-277A
IC1: TPS923654DMTR; VSON-14-1EP_3x4.45mm_P0.65mm_EP1.6x4.2mm_ThermalVias; Mouser Part Number 595-TPS922054DMTR
L1: SRP1770TA-220M; L_Bourns_SRP1770TA_16.9x16.9mm
NT1: NetTie; NetTie-2_SMD_Pad2.0mm
R5: 10K 0402; R_0402_1005Metric
R6: Rfset 160K 0402; R_0402_1005Metric
R7: Rtemp 57K6 0402; R_0402_1005Metric
R8: Rcomp 825ohm 0402; R_0402_1005Metric
R9: 2512 33mR; R_2512_6332Metric
R10: Rovp1 500K 0402; R_0402_1005Metric
R11: Rovp2 10K 0402; R_0402_1005Metric
R12, R13: 0Ω 0402; R_0402_1005Metric
R14: 2512 66mR; R_2512_6332Metric; not fitted

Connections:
/LED Driver/CSN: C14.2, IC1.13 (CSN), R12.1
/LED Driver/CSP: C14.1, IC1.12 (CSP), R13.1
GND: C5.2, C7.2, C8.2, C12.2, C13.1, C15.2, C16.2, IC1.1 (PGND), IC1.2 (AGND), IC1.7 (FAULT), IC1.15 (EP), NT1.1, R6.2, R7.2, R11.1; also elsewhere on the board
LED V+: C17.2, C18.1, C19.1, C20.1, R9.2, R10.2, R13.2, R14.2; also elsewhere on the board
LED_PWM_5V: IC1.6 (EN/PWM); also elsewhere on the board
unnamed: C15.1, C16.1, R8.2
unnamed: C17.1, D1.3 (K), R9.1, R12.2, R14.1
unnamed: IC1.5 (ADIM/HD), R5.2
unnamed: IC1.10 (COMP), R8.1
unnamed: IC1.9 (FSET), R6.1
unnamed: D1.1 (A), D1.2 (A), IC1.14 (SW), L1.2
unnamed: IC1.8 (TEMP), R7.1
unnamed: IC1.11 (UVP), R10.1, R11.2
unnamed: C13.2, IC1.4 (VCC)
VCC: C5.1, C7.1, C8.1, C12.1, IC1.3 (VIN), L1.1, R5.1; also elsewhere on the board

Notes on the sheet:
this cap likely needs to be as close as possible to pin 3
Input should be 3S2P or 6S1P.

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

Board: 2 copper layers, 95.4 x 30.0 mm, 40 parts (0 on the bottom side), 27 nets.

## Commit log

2023-02-20 Initial commit +1
    [EnvLedTorch.kicad_pcb, EnvLedTorch.kicad_sch, EnvLedTorch_bom_jlc.csv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]
2023-03-12 created lower cost single cell variant with less leds, this version will draw 1.2A possibly more due to losses and what not but can charge at 1.5A
    [EnvLedTorch.kicad_pcb, EnvLedTorch.kicad_sch, EnvLedTorch_bom_jlc.csv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]
2023-03-12 changed LEDs over to a standard format to make the board cheaper
    [Kicad - 1S 2.0.kicad_pcb, Kicad - 1S 2.0.kicad_sch]
2023-03-13 small fix to gitignore to allow gerber CSVs
    [Kicad - 1S 2.0.kicad_pcb, Kicad - 1S 2.0_bom_jlc.csv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]
2023-03-19 broke up 3SV1 into two separate boards (unfinished work)
    [EnvLedTorch.kicad_pcb, EnvLedTorch.kicad_sch, EnvLedTorch_bom_jlc.csv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]
2023-03-20 Finished up LED PCB and made some small tweaks and fixes to main board.
    [EnvLedTorch.kicad_pcb, LedBoard.kicad_pcb, LedBoard.kicad_sch]
2023-04-01 swapped around some parts and re-routed various bits and generated gerbers
    [Kicad - 1S 2.0.kicad_pcb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]
2023-08-24 swapped the switch for pin headers so a switch can be wired externally to the PCB.
    [Kicad - 1S 2.0.kicad_pcb, LedBoard.kicad_pcb, LedBoard.kicad_sch]
2023-09-18 started work on adding USB PD 100W support.
    [EnvLedTorch.kicad_sch]
2023-09-18 drew up the schematic to match the reference design from TI for 100W PD charger
    [EnvLedTorch.kicad_sch]
2023-09-19 added TVS2200 to schematic matching the reference design.
    [EnvLedTorch.kicad_sch]
2023-09-19 updated all symbols to match BOM
    [EnvLedTorch.kicad_sch]
2023-09-19 updated inductors.
    [EnvLedTorch.kicad_sch]
2023-09-19 C35 had wrong footprint, changed from 0603 to 0402
    [EnvLedTorch.kicad_sch]
2023-09-21 few small corrections i forgot to commit
    [EnvLedTorch.kicad_sch]
2023-12-31 Added a note in schematic, Current version is capable of 45W and isnt advised for 65W or more, I should change the IC out.
    [EnvLedTorch.kicad_sch]
2024-02-03 Added new footprint for smaller cheaper, newer led.
    [LedBoard.kicad_pcb, LedBoard.kicad_sch]
2024-03-01 renamed main project folder as this is going to be a single torch instead of two
    [EnvLedTorch.kicad_pcb, EnvLedTorch.kicad_sch, EnvLedTorch_bom_jlc.csv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]
2024-03-01 cleanup of parts no longer intend to use.
    [EnvLedTorch_bom_jlc.csv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]
2024-03-01 swapped regulator, needs leds implemented, osram pure 1414
    [LedBoard.kicad_sch]
2024-03-01 added npn mosfet for led pwm controll
    [LedBoard.kicad_sch]
2024-03-03 added basic io controller PCB
    [IOController.kicad_pcb, IOController.kicad_sch, LedBoard.kicad_sch]
2024-03-03 swapped regulator for 1.8V instead of 5V for lower power
    [IOController.kicad_sch]
2024-03-03 Added library for LED
2024-03-03 updated LED board
    [LedBoard.kicad_pcb, LedBoard.kicad_sch]
2024-03-03 added giant npn mosfet on led board, needs to be removed from controller board
    [LedBoard.kicad_pcb, LedBoard.kicad_sch]
2024-03-10 made some small tweaks
    [LedBoard.kicad_pcb, LedBoard.kicad_sch]
2024-03-10 added some parts to controller board for now.
    [IOController.kicad_sch]
2024-04-04 modified IO board and LED board so they connect together using XT60
    [IOController.kicad_pcb, IOController.kicad_sch, LedBoard.kicad_pcb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]
2024-04-04 replaced traces with zones
    [LedBoard.kicad_pcb]
2024-04-04 corrected VCC and GND being swapped
    [IOController.kicad_pcb, IOController.kicad_sch, LedBoard.kicad_pcb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]
2024-04-04 changed an XT60 to edge connector because I didnt like the XT60 and pin header setup.
    [IOController.kicad_pcb, IOController.kicad_sch, LedBoard.kicad_pcb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]
2024-04-05 added footprints for some discontinued LEDs i have spare of, added level shifter to ensure gate voltage is above threshold
    [IOController.kicad_pcb, IOController.kicad_sch, LedBoard.kicad_pcb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]
2024-04-29 some partial work towards modifying the design yet again
    [IOController.kicad_pcb, IOController.kicad_sch, LedBoard.kicad_sch]
2024-05-02 changed regulator again
    [IOController.kicad_sch, LedDriver.kicad_sch]
2024-05-25 updated LED board to use new LEDs
    [IOController.kicad_sch, LedBoard.kicad_pcb, LedBoard.kicad_sch]
2024-05-25 started re-work of led driver circuit on IO board
    [IOController.kicad_pcb, IOController.kicad_sch, LedDriver.kicad_sch]
2024-05-27 completed circuit, could be laid out better
    [IOController.kicad_pcb, IOController.kicad_sch, LedDriver.kicad_sch]
2024-06-03 laid out the circuit better but less space efficient.
    [IOController.kicad_pcb, LedDriver.kicad_sch]
2024-06-03 renamed some stuff
    [ChargeBoard.kicad_pcb, ChargeBoard.kicad_sch]
2024-06-04 added some notes on which 240W capable ICs to switch to.
    [ChargeBoard.kicad_sch]
2024-07-13 small adjustment to zones and added stitching vias
    [IOController.kicad_pcb]
2024-07-27 updated small changes
    [IOController.kicad_pcb, IOController.kicad_sch, LedDriver.kicad_sch]
2024-09-07 re-organised some files, started work on implementing 100W and 240W EPR versions of the charge board
    [ChargeBoard.kicad_pcb, ChargeBoard.kicad_sch, IOController.kicad_pcb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]
2024-09-15 swapped RP2040 for attiny1634, still requires more work.
    [IOController.kicad_pcb, IOController.kicad_sch, MCU.kicad_sch]
2024-10-24 made some adjustments to improve design reliability.
    [LedBoard.kicad_sch, LedDriver.kicad_sch, MCU.kicad_sch]
2024-10-25 modified design to be closer to reference version.
    [IOController.kicad_pcb, LedDriver.kicad_sch]
2024-10-25 made a few small fixes.
    [IOController.kicad_pcb]
2024-11-04 corrected a few things to make life a bit easier.
    [IOController.kicad_pcb, LedDriver.kicad_sch]
2024-11-21 Started work on a smaller light.
    [BQ25622ERYKR.kicad_sch, BQ25638YBGR.kicad_sch, ChargeBoard.kicad_pcb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]
2025-02-04 updated the schematics and completed the battery charge IC circuit
    [BQ25622ERYKR.kicad_sch, ChargeBoard.kicad_sch, EDC Charge Board.kicad_sch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]
